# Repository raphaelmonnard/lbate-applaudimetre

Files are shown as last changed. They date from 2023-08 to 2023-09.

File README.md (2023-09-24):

# Introduction
*Applaudimètre* is a project in collaboration withe the music band [Lady Bee and The Epileptics](https://www.ladybeeandtheepileptics.com). 

The goal in to create an applause meter for the project *Sondage* with a remote controle fixed on the saxophone.

# Bill of material
## Transmitter (remote control)
* [Pro micro ATMEGA32U4 Module 5V](https://www.aliexpress.com/item/32840365436.html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)
* [1800mAh Lithium Polymer LiPo Battery](https://www.aliexpress.com/i/4000342686226.html)
* [Sparkfun LiPo charger/booster - PRT-14411](https://www.digikey.ch/en/products/detail/sparkfun-electronics/PRT-14411/7725301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)
* [433Mhz RF Wireless Transmitter Module](https://www.aliexpress.com/item/1970487479.html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)
* [433Mhz Antenna Copper Spring](https://www.aliexpress.com/item/4000960125591.html?spm=a2g0o.order_list.order_list_main.137.37cc1802Q5Wayy)
* [0.91 inch OLED Module White OLED 128X32](https://www.aliexpress.com/item/32777216785.html)
* [10 MΩ Linear Taper Rotary Potentiometer Resistor](https://www.aliexpress.com/item/1005002891439915.html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)
* [10 KΩ Linear Log Slide Pot](https://www.aliexpress.com/item/1005001448365017.html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)
* 3x Momentary switch
* 1x Slide switch
* 10K resistance

## Receiver
* [LED stripe WS2815, White PCB, 3m 60 IP30](https://www.aliexpress.com/item/4001322411818.html?spm=a2g0o.order_list.order_list_main.84.37cc1802Q5Wayy)
* [Neon Tube for LED Strip](https://www.aliexpress.com/item/4000095850068.html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)
* [LM2596s DC-DC Step-down Power Supply Module](https://www.aliexpress.com/item/1005003623537411.html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)
* [433Mhz RF Wireless Transmitter Module](https://www.aliexpress.com/item/1970487479.html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)
* [10 MΩ Linear Taper Rotary Potentiometer Resistor](https://www.aliexpress.com/item/1005002891439915.html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)
* [Sparkfun Sound Detector - SEN-12642](https://www.digikey.ch/en/products/detail/sparkfun-electronics/SEN-12642/5762440)
* [Red LED Diode F5](https://www.aliexpress.com/item/1005003483614644.html?spm=a2g0o.order_list.order_list_main.69.37cc1802Q5Wayy)
* [Micro Type USB USB 2.0 Male Connector to Micro Type 2.0 Female Extension](https://www.aliexpress.com/item/1005004622194467.html?spm=a2g0o.order_list.order_list_main.64.37cc1802Q5Wayy)
* [Tchauxduino - custom leonardo ATMEGA32U4 arduino module](https://gitlab.com/bbonnal/tchauduino)
* MOSFET
* Power Switch
* 27 mm wood
* 4 mm Plywood
* 2 mm Plywood for panel interface

# Electrical
## Transmitter
Here is the fritzing diagram and images of the protoboards:

<p float="left">
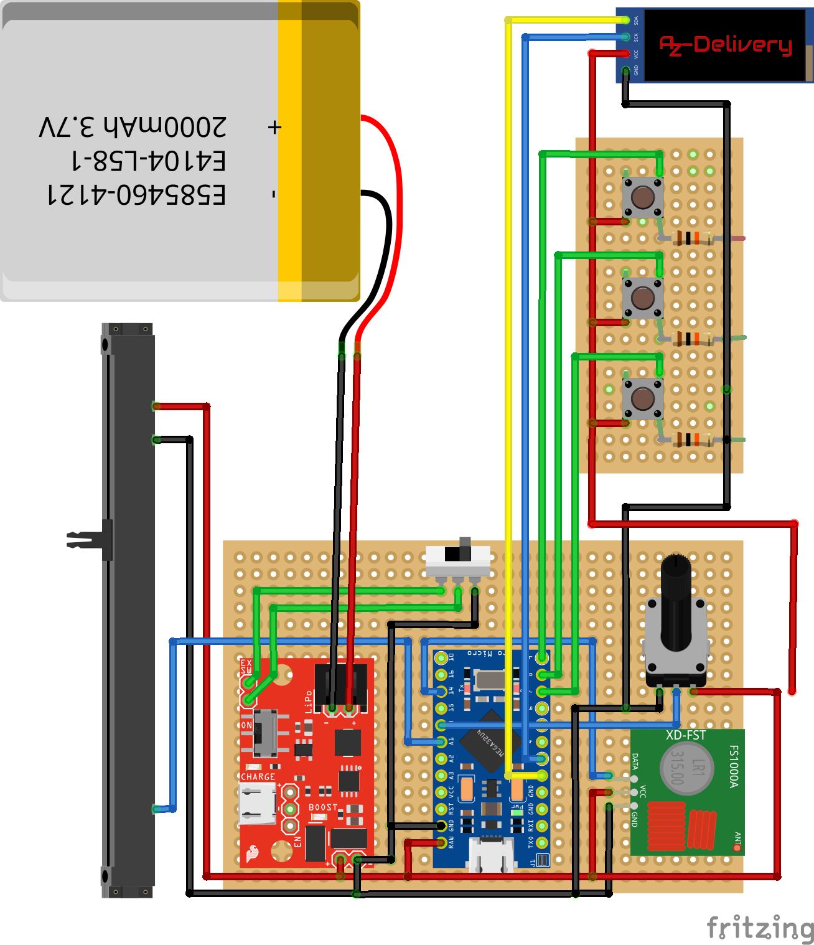
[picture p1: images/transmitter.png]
  
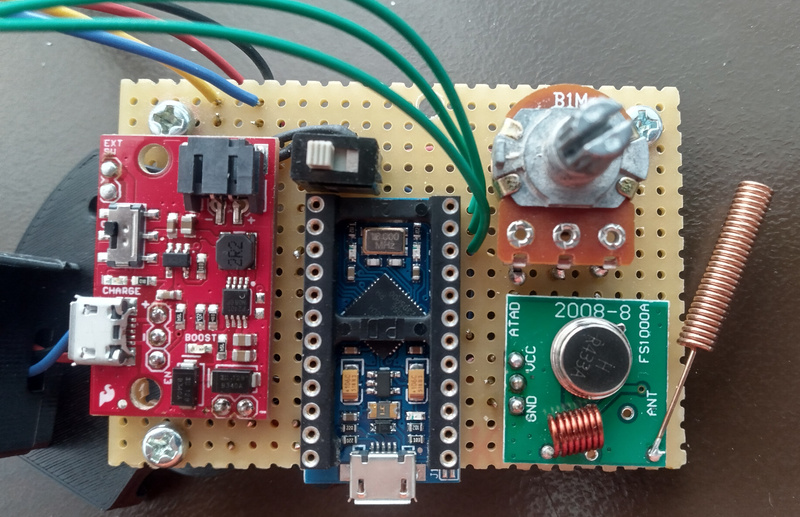
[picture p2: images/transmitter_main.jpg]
  
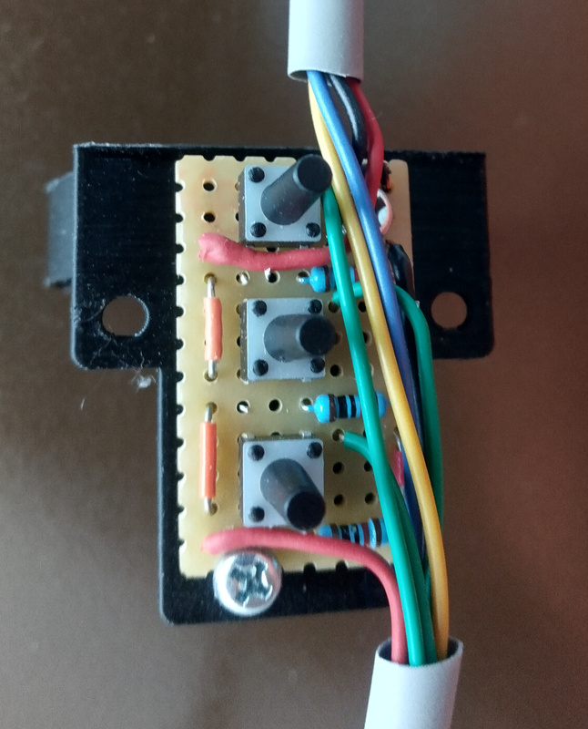
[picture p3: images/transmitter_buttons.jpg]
  
</p>

## Receiver
Here is the fritzing diagram and images of the protoboards:
<p float="left">
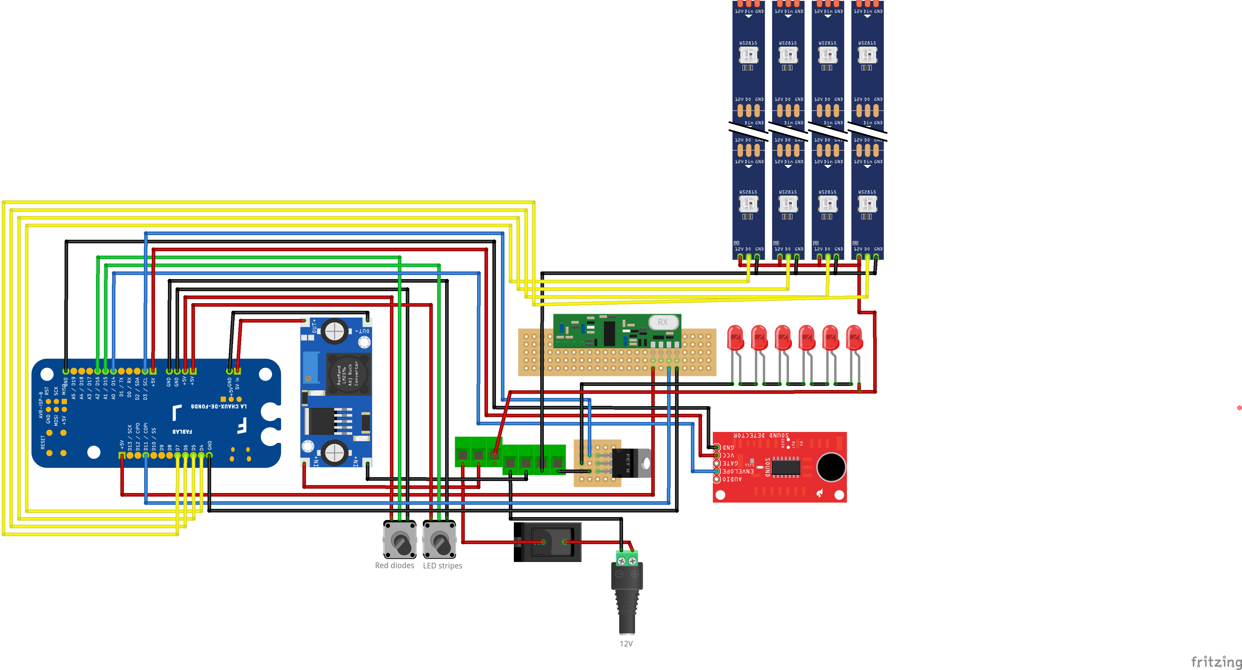
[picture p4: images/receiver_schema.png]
  
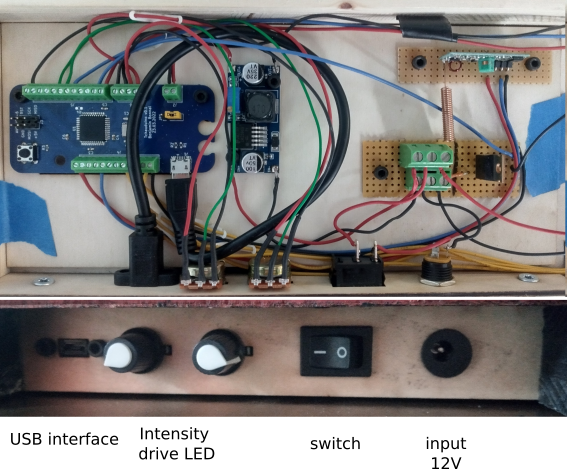
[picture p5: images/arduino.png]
  
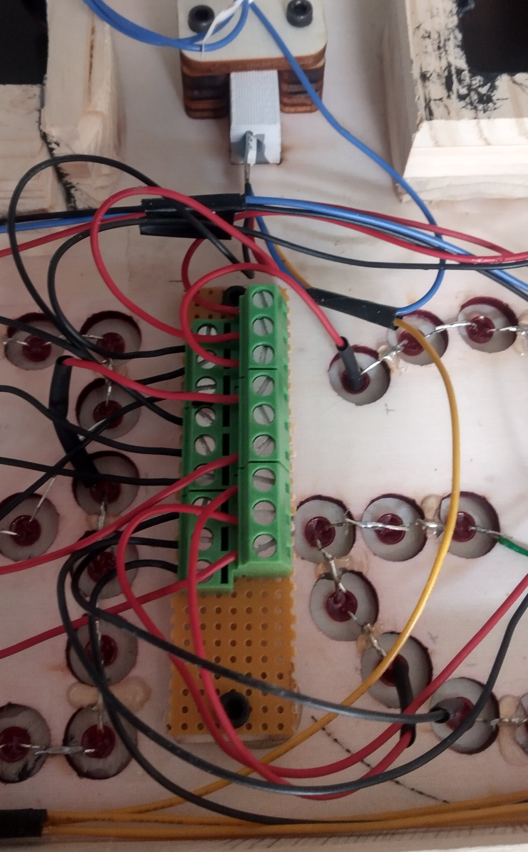
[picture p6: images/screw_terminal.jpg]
  
</p>

The goal was to use a maximum of scew driver terminal to easy fix and disassemble the reveiver.

# Mecanical
## Transmitter
The goal of the mechanical part is to fix the transmitter on the saxophone as a remote control. Custom 3D print is used to perform this: 
<p float="left">
  
  
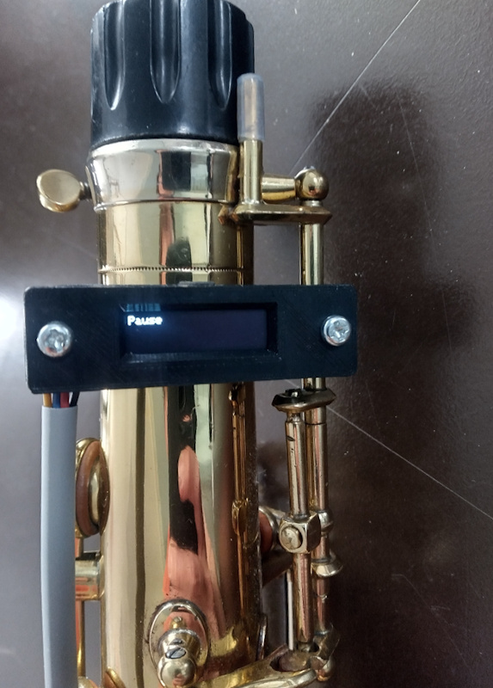
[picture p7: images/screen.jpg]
  
</p>

## Receiver
The goal is to create an applause meter and integrate all the electronics to reveive the signal from the tranmitter and drive the LEDs.

Fusion 360 was use to design the receiver mechanically

<p float="left">
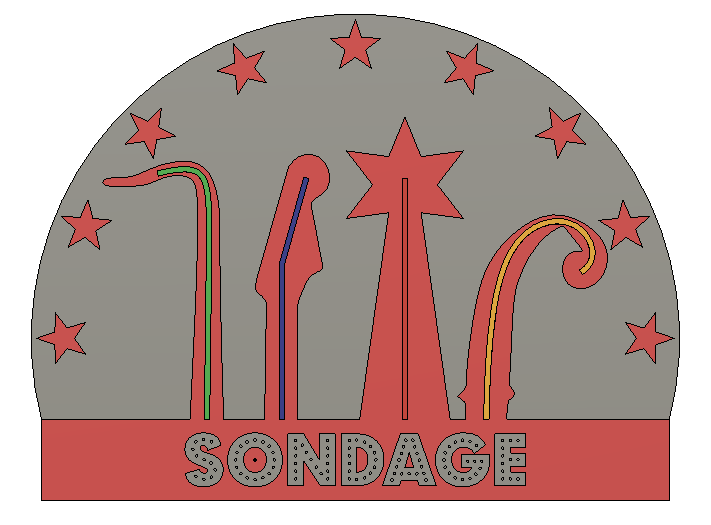
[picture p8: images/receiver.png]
  
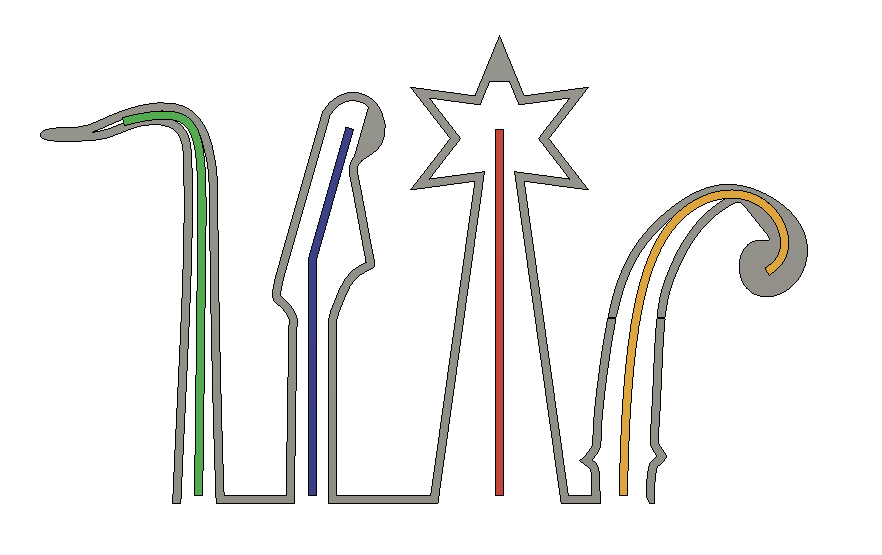
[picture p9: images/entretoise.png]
  
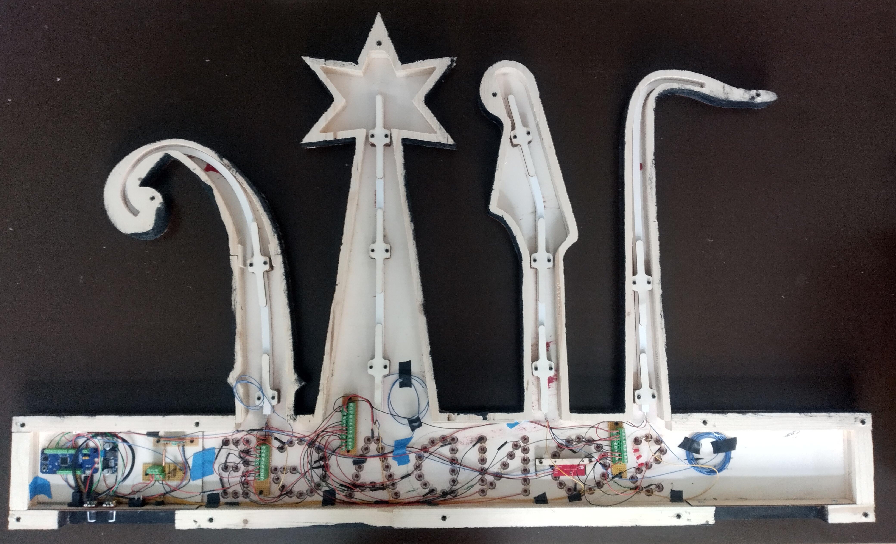
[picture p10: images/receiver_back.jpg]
  
</p>

All woods was processed with a laser cutter (Rayjet R500) except the 27mm spacer (gray part of the center image) with the CNC. For pannels, 2mm woods is used.

# Software
The arduino code can be founded in `software` folder.
In order to create the table, the csv file is edited, and the with the python script `csv-to-h.py`, two `.h` files are created as input for the arduino sketch like:

```mermaid
  graph LR;
      id1[spectacle.csv]
      id2[receiver/spectacle.h]
      id3[transmitter/spectacle.h]
      id1--csv-to-h.py-->id2;
      id1--csv-to-h.py-->id3;
```

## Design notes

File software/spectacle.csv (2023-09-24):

timing | description | CE | JB | LB | SA | weight | max | flag
Test intensité LED | Réglage de l'intensité des LEDs avant le spectacle en fonction des condition de lumière | 100 | 100 | 100 | 100 | 100 | 100 | 1
Test sensibilité du micro | Réglage de la sensibilité du micro en fonction du publique et du bruit ambiant. Il peut être ajuster à la fin de "The way you look tonight" | 100 | 100 | 100 | 100 | 0 | 100 | 5
Pause | Inactive avant spectacle | 0 | 0 | 0 | 0 | 0 | 0 | 7
Introduction | random LEDs. "plus long" | 100 | 100 | 100 | 100 | 0 | 100 | 2
The way you look tonight - avant solo sax | Explosion, les lumières de l’applaudimètre s’allument. | 100 | 100 | 100 | 100 | 0 | 100 | 3
The way you look tonight - fin | Applaudissements | 90 | 80 | 100 | 50 | 50 | 70 | 0
Et en plus, l’applaudimètre fonctionne... c’est super ! | Faire qu'il s'allume après la réplique | 90 | 80 | 100 | 50 | 50 | 70 | 4
En bleu, notre guitariste : Jean-Baptiste De La Touche... | Applaudissements, la colonne bleue s’allume | 0 | 100 | 0 | 0 | 50 | 70 | 0
En vert, notre saxophoniste : Charles Edouard von Bourdon... | Applaudissements, la colonne verte s’allume | 100 | 0 | 0 | 0 | 50 | 70 | 0
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

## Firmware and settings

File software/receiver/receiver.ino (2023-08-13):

#include <SPI.h> // Not actually used but needed to compile
#include <avr/pgmspace.h>
#include "spectacle.h"
#include <RH_ASK.h>
#include <FastLED.h>

// #include "SSD1306Ascii.h"
// #include "SSD1306AsciiAvrI2c.h"

// // 0X3C+SA0 - 0x3C or 0x3D
// #define I2C_ADDRESS 0x3C

// // Define proper RST_PIN if required.
// #define RST_PIN -1

// SSD1306AsciiAvrI2c oled;

#define NUM_LEDS_CE 33
#define DATA_PIN_CE 7
// #define COLOR_CE 0x0EA500
#define COLOR_CE 0xFF3000
CRGB leds_CE[NUM_LEDS_CE];

#define NUM_LEDS_JB 28
#define DATA_PIN_JB 6
// #define COLOR_JB 0x0045E5
#define COLOR_JB 0xFFFF00
CRGB leds_JB[NUM_LEDS_JB];

#define NUM_LEDS_LB 28
#define DATA_PIN_LB 5
// #define COLOR_LB 0xD200AB
#define COLOR_LB 0xFF00FF
CRGB leds_LB[NUM_LEDS_LB];

#define NUM_LEDS_SA 34
#define DATA_PIN_SA 4
// #define COLOR_SA 0xE5DD00
#define COLOR_SA 0x00AAFF
CRGB leds_SA[NUM_LEDS_SA];

struct DataPacket {
  int channel = 0;
  int ledHeightPotValue = 0;
  int micSensitivity = 0;
  bool display = false;
};

// Adafruit_SSD1306 display(128, 32, &Wire, -1);
RH_ASK driver;
DataPacket packet;
int memoryFlag = 0;
int memoryMillis = millis();
int brightness = 0;
int channel = 0;
int ledHeightPotValue = 100;
int micSensitivity = 1023;
int micLowerThreshold = 90;
bool display = false;

const int attackTime = 100;     // Attack time in milliseconds
const int decayTime = 1800;      // Decay time in milliseconds
const int sustainLevel = 0;    // Sustain level
const int releaseTime = 2000;    // Release time in milliseconds

unsigned long startTime;         // Time when the note starts
int initialValue;
int envelopeValue = 0;           // Current value of the envelope signal$

int B;

// void updateDisplay(const String& text) {
//   display.clearDisplay();
//   display.setCursor(0, 0);
//   display.println(text);
//   display.display();
// }

void setLEDs(CRGB* leds, int numLeds, int scaledValue, CRGB color) {
  for (int i = 0; i < numLeds; i++) {
    leds[i] = (i < scaledValue) ? color : CRGB::Black;
  }
}

template <uint8_t DATA_PIN, CRGB* leds, int numLeds>
void setupLeds() {
  FastLED.addLeds<WS2812, DATA_PIN, RGB>(leds, numLeds);
  pinMode(DATA_PIN, OUTPUT);
}

void randomLEDs(CRGB* leds, int numLeds) {
  if (random(4)==1){
    for (int i = 0; i < numLeds; i++){
      leds[i] = CRGB::Black;
    }
  }
  
  int randomIndex = random(numLeds);
  
  // Generate random RGB values for the color components
  byte randomRed = random(256);
  byte randomGreen = random(256);
  byte randomBlue = random(256);

  // Assign the random color to the selected LED
  leds[randomIndex] = CRGB(randomRed, randomGreen, randomBlue);
}

void upLEDs(CRGB* leds, int numLeds, CRGB color){
    for (int i = 0; i < numLeds; i++){
      leds[i] = color;
      FastLED.show();
      delay(10);
  }
}

void blinkLEDs(){
  for (int i = 0; i<3; i++ ) {
    FastLED.setBrightness(0);
    FastLED.show();
    delay(200);
    FastLED.setBrightness(brightness);
    FastLED.show();
    delay(200);
  }
}

void setup() {
  Serial.begin(9600);
  if (!driver.init())
    Serial.println("init failed");

  // #if RST_PIN >= 0
  //   oled.begin(&Adafruit128x32, I2C_ADDRESS, RST_PIN);
  // #else // RST_PIN >= 0
  //   oled.begin(&Adafruit128x32, I2C_ADDRESS);
  // #endif // RST_PIN >= 0
  //   // Call oled.setI2cClock(frequency) to change from the default frequency.

  // oled.setFont(Adafruit5x7);

  // oled.clear();

  // // first row
  // oled.println("set1X test");

  // if (!display.begin(SSD1306_SWITCHCAPVCC, 0x3C)) {
  //   Serial.println(F("SSD1306 allocation failed"));
  //   for (;;) {}
  // }
  // display.display();
  // delay(500);
  // display.setTextSize(1);
  // display.setTextColor(SSD1306_WHITE);

  setupLeds<DATA_PIN_CE, leds_CE, NUM_LEDS_CE>();
  setupLeds<DATA_PIN_JB, leds_JB, NUM_LEDS_JB>();
  setupLeds<DATA_PIN_LB, leds_LB, NUM_LEDS_LB>();
  setupLeds<DATA_PIN_SA, leds_SA, NUM_LEDS_SA>(); 
}

void loop() {
  // updateDisplay("Spectacle");
  // Serial.println("start loop");

  // Adjust brightness of stripe LED
  if (memoryFlag == 3 || memoryFlag == 6 ) {
    brightness = 0;
  } else if (memoryFlag == 8){
    if (display){
      Serial.print("brightness to 255");
      brightness = map(analogRead(A1), 0, 1023, 0, 255);
    }
    else {
      Serial.print("brightness to 0");
        brightness = 0;
    }
  } else {
    brightness = map(analogRead(A1), 0, 1023, 0, 255);
  }
  FastLED.setBrightness(brightness);

  // update brightness for the red LED diodes, 
  // output PIN 3 (required to avoid conflict wiht RadioHead)
  // Analog sensor A2
  if (memoryFlag == 6 || memoryFlag == 7){
    analogWrite(3, 0);
  }
  else{
    analogWrite(3, map(analogRead(A2), 0, 1023, 0, 255));
  }

  if (driver.available()) {
    uint8_t buf[RH_ASK_MAX_MESSAGE_LEN];
    uint8_t buflen = sizeof(buf);
    if (driver.recv(buf, &buflen) && buflen == sizeof(packet)) {
      memcpy(&packet, buf, sizeof(packet));
      ledHeightPotValue = packet.ledHeightPotValue;
      channel = packet.channel;
      micSensitivity = packet.micSensitivity;
      display = packet.display;
    }
    FastLED.show();
  }

  int flag = pgm_read_word(&(params[channel][6]));
  // auto control LEDs withou ledHeightPotValue
  if (flag == 5){  
    ledHeightPotValue = 100;
  }

  // Test intensité LED  
  if (flag == 1) {
    setLEDs(leds_CE, NUM_LEDS_CE, 100, COLOR_CE);
    setLEDs(leds_JB, NUM_LEDS_JB, 100, COLOR_JB);
    setLEDs(leds_LB, NUM_LEDS_LB, 100, COLOR_LB);
    setLEDs(leds_SA, NUM_LEDS_SA, 100, COLOR_SA);  
  }
  
  // Introduction - random LEDs  
  else if (flag == 2) {
    randomLEDs(leds_CE, NUM_LEDS_CE);
    randomLEDs(leds_JB, NUM_LEDS_JB);
    randomLEDs(leds_LB, NUM_LEDS_LB);
    randomLEDs(leds_SA, NUM_LEDS_SA);
    delay(random(50, 200));
  }

  // Explosion, les lumières de l’applaudimètre s’allument.
  else if (flag == 3) {
    if (memoryFlag != 3) {
      FastLED.clear();
      FastLED.show();
      upLEDs(leds_CE, NUM_LEDS_CE, COLOR_CE);
      upLEDs(leds_JB, NUM_LEDS_JB, COLOR_JB);  
      upLEDs(leds_LB, NUM_LEDS_LB, COLOR_LB);  
      upLEDs(leds_SA, NUM_LEDS_SA, COLOR_SA);
      blinkLEDs();
    }
  }

  // Coup de téléphone - clignoter ou "Et en plus, l’applaudimètre fonctionne... c’est super !"
  else if (flag == 4) {
    setLEDs(leds_CE, NUM_LEDS_CE, 100, COLOR_CE);
    setLEDs(leds_JB, NUM_LEDS_JB, 100, COLOR_JB);
    setLEDs(leds_LB, NUM_LEDS_LB, 100, COLOR_LB);
    setLEDs(leds_SA, NUM_LEDS_SA, 100, COLOR_SA);
    blinkLEDs();
  }

  else if (flag == 6){
    if (memoryFlag != 6) {
      setLEDs(leds_CE, NUM_LEDS_CE, 100, COLOR_CE);
      setLEDs(leds_JB, NUM_LEDS_JB, 100, COLOR_JB);
      setLEDs(leds_LB, NUM_LEDS_LB, 100, COLOR_LB);
      setLEDs(leds_SA, NUM_LEDS_SA, 100, COLOR_SA);  
      blinkLEDs();

      setLEDs(leds_CE, NUM_LEDS_CE, 100, COLOR_CE);
      setLEDs(leds_JB, NUM_LEDS_JB, 100, COLOR_JB);
      setLEDs(leds_LB, NUM_LEDS_LB, 100, COLOR_LB);
      setLEDs(leds_SA, NUM_LEDS_SA, 100, COLOR_SA); 
      
      for (int i=255; i>=0; i=i-2){
        FastLED.setBrightness(i);
        FastLED.show();
        analogWrite(3, i);     
      }

      FastLED.setBrightness(255);

      for (int i=0; i<10; i++){
        randomLEDs(leds_CE, NUM_LEDS_CE);
        randomLEDs(leds_JB, NUM_LEDS_JB);
        randomLEDs(leds_LB, NUM_LEDS_LB);
        randomLEDs(leds_SA, NUM_LEDS_SA);
        FastLED.show();        
        analogWrite(3, random(255));
        delay(random(500));
        analogWrite(3, 0);
        delay(random(500));
      }
    }            
  }

  else if (flag == 8) {
    setLEDs(leds_CE, NUM_LEDS_CE, 100, COLOR_CE);
    setLEDs(leds_JB, NUM_LEDS_JB, 100, COLOR_JB);
    setLEDs(leds_LB, NUM_LEDS_LB, 100, COLOR_LB);
    setLEDs(leds_SA, NUM_LEDS_SA, 100, COLOR_SA);
  }
  
  else{
    int weight_CE = pgm_read_word(&(params[channel][0]));
    int weight_JB = pgm_read_word(&(params[channel][1]));
    int weight_LB = pgm_read_word(&(params[channel][2]));
    int weight_SA = pgm_read_word(&(params[channel][3]));
    int weight = pgm_read_word(&(params[channel][4]));
    int max = pgm_read_word(&(params[channel][5]));

    // compute factor for potentiometer value (0-100)
    int A = weight * ledHeightPotValue / 100; 

    // compute factor for mic (0-100)
    int micValue = analogRead(A0);

    //ensure lower limit: 
    if (micValue < micLowerThreshold) {
      micValue = micLowerThreshold;
    }

    //ensure higher limit: 
    if (micValue > micSensitivity) {
      micValue = micSensitivity;
    }

    int mic = map(micValue, micLowerThreshold, micSensitivity, 0, 100); // scaled value of mic with micSensitivity
    
    if (mic>0) {
      // Start the note and reset the envelope
      startTime = millis();
      // update initial value only if mic signal is higher
      if (mic > initialValue) {
        initialValue = mic;
      }
    }

    // Calculate the time since the note started
    unsigned long currentTime = millis();
    unsigned long elapsedTime = currentTime - startTime;

    // Generate the envelope signal
    if (elapsedTime < attackTime) {
      // Attack phase
      envelopeValue = map(elapsedTime, 0, attackTime, initialValue, 100);
    } else if (elapsedTime < (attackTime + decayTime)) {
      // Decay phase
      envelopeValue = map(elapsedTime, attackTime, attackTime + decayTime, 100, sustainLevel);
    } else {
      // Release phase
      unsigned long releaseElapsedTime = elapsedTime - (attackTime + decayTime);
      envelopeValue = map(releaseElapsedTime, 0, releaseTime, sustainLevel, 0);
      initialValue = 0;
    }

    B = ledHeightPotValue / 100.0 * (100 - weight) * initialValue / 100.0 * envelopeValue / 100.0;

    // scale with max value (0-100)
    int C = map(A + B, 0, 100, 0, max);

    // compute the number of LED powered ON for each musician
    int scaledValue_CE = map(C * weight_CE / 100.0, 0, 100, 0, NUM_LEDS_CE);
    int scaledValue_JB = map(C * weight_JB / 100.0, 0, 100, 0, NUM_LEDS_JB);
    int scaledValue_LB = map(C * weight_LB / 100.0, 0, 100, 0, NUM_LEDS_LB);
    int scaledValue_SA = map(C * weight_SA / 100.0, 0, 100, 0, NUM_LEDS_SA);

    // update the LED controlers
    setLEDs(leds_CE, NUM_LEDS_CE, scaledValue_CE, COLOR_CE);
    setLEDs(leds_JB, NUM_LEDS_JB, scaledValue_JB, COLOR_JB);
    setLEDs(leds_LB, NUM_LEDS_LB, scaledValue_LB, COLOR_LB);
    setLEDs(leds_SA, NUM_LEDS_SA, scaledValue_SA, COLOR_SA);

    // Serial.print("\t A: ");
    // Serial.print(A);
    // Serial.print("\t ledHeightPotValue: ");
    // Serial.print(ledHeightPotValue);
    // Serial.print("\t envelopeValue: ");
    // Serial.print(envelopeValue);
    // Serial.print("\t weight: ");
    // Serial.print(weight);  
    // Serial.print("\t mic: ");
    // Serial.print(mic);
    // Serial.print("\t initialValue: ");
    // Serial.print(initialValue);
    // Serial.print("\t B: ");
    // Serial.print(B);
    // Serial.print("\t C: ");
    // Serial.println(C);
    // Serial.print("\t scaledValue_CE: ");
    // Serial.println(scaledValue_CE);
    // Serial.print("\t weight: ");
    // Serial.println(weight);
  }

  Serial.print("channel: ");
  Serial.println(channel);

  memoryFlag = flag;
  // int currentMillis= millis();
  // Serial.println(millis()-memoryMillis);
  // memoryMillis = currentMillis;

}

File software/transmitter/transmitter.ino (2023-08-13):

#include <SPI.h> // Not actually used but needed to compile
#include <avr/pgmspace.h>
#include "spectacle.h"

// Init RadioHead for transmission
#include <RH_ASK.h>
RH_ASK driver(2000, 11, 14, 9);

// Init display
#include <Adafruit_GFX.h>
#include <Adafruit_SSD1306.h>
#define SCREEN_WIDTH 128 // OLED display width, in pixels
#define SCREEN_HEIGHT 32 // OLED display height, in pixels

// Declaration for an SSD1306 display connected to I2C (SDA, SCL pins)
#define OLED_RESET -1 // Reset pin # (or -1 if sharing Arduino reset pin)
Adafruit_SSD1306 display(SCREEN_WIDTH, SCREEN_HEIGHT, &Wire, OLED_RESET);

unsigned long activationTime = 0;
const unsigned long activationDuration = 3000;

#define BTN_next 8
#define BTN_previous 7
#define BTN_disp 9

int btn_next = LOW;
int btn_previous = LOW;
int memory_next_btn = LOW;
int memory_previous_btn = LOW;
bool memory_btn_next_flag = false;
bool memory_btn_previous_flag = false;

struct DataPacket {
  int channel = 0;
  int ledHeightPotValue = 0;
  int micSensitivity = 0;
  bool display = false;
};

DataPacket currentPacket;
DataPacket previousPacket;

int channel = 0;                  // Initial channel selection
int rows = sizeof(desc) / sizeof(desc[0]);

char buffer[255];

void updateDisplay(const char* text) {
  display.clearDisplay();
  display.setCursor(0, 0);
  display.println(text);
  display.display();
}

void setup()
{
  Serial.begin(9600);	  // Debugging only
  if (!driver.init()) {
    Serial.println("RF module initialization failed!");
  }

  // SSD1306_SWITCHCAPVCC = generate display voltage from 3.3V internally
  if(!display.begin(SSD1306_SWITCHCAPVCC, 0x3C)) { 
    Serial.println(F("SSD1306 allocation failed"));
    for(;;); // Don't proceed, loop forever
  }
  // Show initial display buffer contents on the screen --
  // the library initializes this with an Adafruit splash screen.
  display.display();
  delay(500);
  display.setTextSize(1);
  display.setTextColor(SSD1306_WHITE);

  pinMode(BTN_next, INPUT_PULLUP);
  pinMode(BTN_previous, INPUT_PULLUP);
}

void loop()
{
  // Update the current packet
  currentPacket.ledHeightPotValue = map(analogRead(A1), 0, 1023, 0, 100);
  currentPacket.micSensitivity = analogRead(A0);
  currentPacket.display = digitalRead(BTN_disp);
  Serial.print("Selected disp: ");
  Serial.println(currentPacket.display);

  if (currentPacket.display==1) {
    activationTime = millis();
    updateDisplay(buffer);
  }
    
  btn_next = digitalRead(BTN_next);
  if (btn_next == LOW && !memory_btn_next_flag) {
    currentPacket.channel = (currentPacket.channel + 1) % rows;
    Serial.print("Selected Channel: ");
    Serial.println(currentPacket.channel);
    strcpy_P(buffer, (char *)pgm_read_word(&(desc[currentPacket.channel])));  // Necessary casts and dereferencing, just copy.
    memory_btn_next_flag = true;
    
    activationTime = millis();  // Record the time when the button is pressed
    updateDisplay(buffer);
  } else if (btn_next == HIGH) {
    memory_btn_next_flag = false;
  }

  btn_previous = digitalRead(BTN_previous);
  if (btn_previous == LOW && !memory_btn_previous_flag) {
    currentPacket.channel = (currentPacket.channel + rows - 1) % rows;
    Serial.print("Selected Channel: ");
    Serial.println(currentPacket.channel);
    strcpy_P(buffer, (char *)pgm_read_word(&(desc[currentPacket.channel])));  // Necessary casts and dereferencing, just copy.
    memory_btn_previous_flag = true;
    
    activationTime = millis();  // Record the time when the button is pressed
    updateDisplay(buffer);
  } else if (btn_previous == HIGH) {
    memory_btn_previous_flag = false;
  }
  
  // Compare with the previous packet
  if (memcmp(&currentPacket, &previousPacket, sizeof(DataPacket)) != 0) {
    // If the packets are different, send the current packet
    driver.send((uint8_t*)&currentPacket, sizeof(DataPacket));
    driver.waitPacketSent();
    Serial.println("Package sent !");
    
    // Update the previous packet
    memcpy(&previousPacket, &currentPacket, sizeof(DataPacket));
  }

  // Check if activation duration has passed
  if (millis() - activationTime >= activationDuration) {
    display.clearDisplay();  // Deactivate the screen
    display.display();
  }
}

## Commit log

2023-06-10 init ino files
    [spectacle.csv]
2023-06-10 Init KiCad files
    [arduino.kicad_pcb, arduino.kicad_sch]
2023-06-10 Auto switch off screen
2023-06-10 Add LED color for musicians
2023-06-11 rescale full value to avoid blink
    [transmitter.ino]
2023-06-11 add weight and max values
    [spectacle.csv]
2023-06-11 add display and switch button
2023-06-28 update pin IO
2023-06-28 update void loop for LED integrations
2023-06-28 add all musicians LEDs
2023-07-05 Add brightness for red LEDs
2023-07-08 Fix number of LEDs per musician
    [receiver.ino]
2023-07-09 working code with blink
    [spectacle.csv]
2023-07-09 Applause metter broken
    [spectacle.csv]
2023-07-09 fix applause metter broken
    [receiver.ino]
2023-07-09 remove redligh col
    [spectacle.csv]
2023-08-02 ajust pin for pro micro
2023-08-13 ajuste valeur SA
    [spectacle.csv]
2023-08-13 Add hé Ho
    [spectacle.csv]
2023-08-13 Ajout des étapes de bis
    [spectacle.csv]
2023-08-13 Enlevé applaudimètre cassé
    [spectacle.csv]
2023-09-24 clean electic folder
    [arduino.kicad_pcb, arduino.kicad_sch, receiver.fzz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]
2023-09-24 fix quotes
    [spectacle.csv]
2023-09-24 add mosfet
2023-09-24 rename fitring
    [receiver.fzz, tranmitter.fzz]
